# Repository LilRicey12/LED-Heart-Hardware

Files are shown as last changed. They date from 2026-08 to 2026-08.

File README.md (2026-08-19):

# Hardware-Only Sequential LED Heart

## Project Status

Final Build

## Project Overview

This project involves designing and constructing a heart-shaped sequential LED display using hardware timing and digital logic rather than a programmable microcontroller.

A 555 timer will generate the clock signal, and a CD4017 decade counter will control the LED sequence. The final circuit will be transferred from a breadboard prototype to permanent construction and installed in a finished enclosure.

## Project Goals

* Design a repeating sequential LED effect
* Build the circuit without a microcontroller
* Learn how the 555 timer and CD4017 operate
* Test each circuit subsystem independently
* Transfer the working design to perfboard
* Produce a clean and reliable final assembly
* Document the complete engineering process

## Planned System

Power supply → 555 timer → CD4017 counter → LED output circuitry → Heart-shaped display

## Documentation

This repository will contain:

* Session logs
* Circuit calculations
* Schematics and block diagrams
* Breadboard prototypes
* Test results
* Troubleshooting records
* Perfboard layouts
* Construction photographs
* Final portfolio materials

## Current Stage

The local project workspace, OneDrive archive, and private GitHub repository have been established. Circuit development has not yet begun.

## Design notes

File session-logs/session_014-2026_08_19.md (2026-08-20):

# LED Heart — Session Log

## Session Information

**Session number:** 014
**Date:** 2026-08-19
**Time spent:** 7.5 Hours
**Project phase:** Final Build

## Objective

Finisht the circuit including a power supply and switch

## Starting Point

The majority of the circuit was complete. I had 30 underboard wires to connect and the battery/switch

## Work Completed

* Connected all wire nodes to corresponding resistor
* Practised connecting a battery and switch on scrap protoboard
* Connected battery and the switch to main board

## Engineering Decisions

### Decision Made

N/A

### Reasoning

N/A

## Calculations and Predictions

**Calculation or prediction:** N/A

**Expected result:** N/A

**Actual result:** N/A

## Testing

**What was tested:** Tested the circuit before completion

**How it was tested:** Roughly half way through connecting the nodes I connected the board to power to see if it was working

**Expected result:** Some of the LED's would turn on with the sequencing logic

**Observed or measured result:** The LED's did turn on with the logic, first try too

**Pass or fail:** Pass

## Problems Encountered

N/A

## Troubleshooting Process

N/A

## Changes Made

N/A

## Current Status

### Working

* The entire electrical component of the board is working

### Not Yet Working

* I need to assemble the case and fasteners for the perfboard

### Remaining Questions

* Its all just finishing up, everything I need to know I already now

## Next Session

Assemble the case/frame and connect the board

## Files Created or Updated

* Schematics: N/A
* Calculations: N/A
* Test results: N/A
* Photos: Added 5 photos and 4 videos to raw media folder
* Other: N/A

## Session Summary

This is extremely exciting, I'm actually so happy my perfboard layout actually worked. Overall today was an amazing session.

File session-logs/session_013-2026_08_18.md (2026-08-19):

# LED Heart — Session Log

## Session Information

**Session number:** 013
**Date:** 2026-08-18
**Time spent:** 10 Hours
**Project phase:** Final Build

## Objective

Get as much work done on the final project as possible

## Starting Point

I had practised soldering techniques, planned extensively, mentally preped myself for the final build

## Work Completed

* Complete the LED Heart Hardware up both ICs, full component layout, rails, and mostly connected everything. The only things not connected are Q outputes and diode node to resistors. A total of 30 LEDs
*
*

## Engineering Decisions

### Decision Made

Finish as much as I could today

### Reasoning

This decision is mostly a deadline thing. This LED Heart is a portfolio project yes, but it is also a gift. It is a gift that needs to be ready in 3 days. If I didn't just say "fuck it" and dedicate a full day I believe the deadline would not be met.

## Calculations and Predictions

**Calculation or prediction:** N/A

**Expected result:** N/A

**Actual result:** N/A

## Testing

**What was tested:** N/A

**How it was tested:** N/A

**Expected result:** N/A

**Observed or measured result:** N/A

**Pass or fail:** N/A

## Problems Encountered

* Soldered an LED backwards.
* Lifted a copper pad
* Accidentally misassigned the GND/PWR rails opposite to my perfboard layout
* Tried testing the oscillating output circuit without the IC in the socket..
* Had some weird reading on the oscillating output circuit

## Troubleshooting Process

* Who ever made solder wick needs a nobel prize
* I had to use a small solid core wire to bridge across the lifted pad
* This was actually a large headache. By the time I noticed all the LEDs and capacitors were wired to "GND". It became a decision of undo all of that work, or improivse my design. I ended up improvising my design, the to IC circuits are now slightly different then how they are in the layout. Depending on how things go I plan to update the layout with the new design before closing the project
* This was annoying as well. I was checking the output with a multimetre and the value kept oscillating between 3.1 and 3.7. I found this odd so I made a small led circuit on a breadboard and connected it to the output and it worked perfectly. After some research I found that my multimetre could not keep up with how fast the oscillating was so it was averaging a value. That is what caused the weird readings.

## Changes Made

Some on the fly changes needed to be made because of my mistake. Design layout for the to IC are now different then the perfboard layout

## Current Status

### Working

* Oscillating circuit is the only thing I've explicit verified works, but the LEDs and fade should both work

### Not Yet Working

* The CD4017 outputs have not been connected, as well as the diode node to the resistors for the LED

### Remaining Questions

* The only thing im a bit ambigiuos about it how I am going to install the switch, battery, and frame/case for the perfboard

## Next Session

Next session will be completing the full circuit. This mainly includes hooking up 30 wires and connecting the battery/switch

## Files Created or Updated

* Schematics: N/A
* Calculations: N/A
* Test results: N/A
* Photos: Added 12 photos and 1 video to raw-media folder
* Other: N/A

## Session Summary

This was a long one. Honestly though it was very enjoyable, I found myself more engaged with this session then any others. Something about the almost month of work I put into this coming into its finale is very special. I can't wait to get back at it tomorrow, one step closer to the closing this project.

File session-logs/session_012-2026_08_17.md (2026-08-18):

# LED Heart — Session Log

## Session Information

**Session number:** 012
**Date:** 2026-08-17
**Time spent:** 3 Hours
**Project phase:** Prototyping

## Objective

Fully solder the NE555 oscillating output circuit

## Starting Point

I had the NE555 timer fully modelled on a digital perfboard

## Work Completed

* Completely soldered the NE555 timer circuit
*
*

## Engineering Decisions

### Decision Made

N/A

### Reasoning

N/A

## Calculations and Predictions

**Calculation or prediction:** N/A

**Expected result:** N/A

**Actual result:** N/A

## Testing

**What was tested:** Creating the NE555 timer circuit

**How it was tested:** Reading a blueprint and soldering

**Expected result:** I would get it working

**Observed or measured result:** I got it working

**Pass or fail:** Pass

## Problems Encountered

* I accidently soldered discharge to the wrong node
* I accidently soldered threshold to the wrong node
* The LED turned on but didnt blink

## Troubleshooting Process

* Solderwick, solder-sucker, and struggle
* Solderwick, solder-sucker, and struggle
* I didn't have a clean connection from the resistor to power rail, this caused the capacitor not to get charged. Since the voltage never got over 1/3 Vcc trigger never triggered.

## Changes Made

No changes in the project as a whole

## Current Status

### Working

* NE555 Timer circuit practise

### Not Yet Working

* Main board hasn't been started

### Remaining Questions

* Will it be alright to use solder as connections under the board. How do I properly solder jumper wires under the board

## Next Session

Practise more soldering. Potentially start the main soldering

## Files Created or Updated

* Schematics: N/A
* Calculations: N/A
* Test results: N/A
* Photos: Added some pictures of the soldered NE555 in my raw-media folder
* Other: N/A

## Session Summary

Soldering is hard man. Although with enough patience it is definetly manageable. I ended up having to some particulary tight connections and joints. It all ended up working quite well though. The biggest issue was just trying to connect a 2D layout to a 3D board.

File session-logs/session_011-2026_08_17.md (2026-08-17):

# LED Heart — Session Log

## Session Information

**Session number:** 011
**Date:** 2026-08-17
**Time spent:** 5 Hours
**Project phase:** Modelling

## Objective

Create a final perfboard layout for the heart

## Starting Point

A breadboarded full circuit of the heart was made

## Work Completed

* Finished the perfboard layout for the project
*
*

## Engineering Decisions

### Decision Made

N/A

### Reasoning

N/A

## Calculations and Predictions

**Calculation or prediction:** N/A

**Expected result:** N/A

**Actual result:** N/A

## Testing

**What was tested:** N/A

**How it was tested:** N/A

**Expected result:** N/A

**Observed or measured result:** N/A

**Pass or fail:** N/A

## Problems Encountered

More or less the only problem was trying to keep the board organized well designing it. Having 20 LEDs, 20 resistors, 10 capacitors, 10 dioes. Among other things makes things messy quick. In all honesty its not cleanest even after being completed

## Troubleshooting Process

N/A

## Changes Made

No changes the the design have been made

## Current Status

### Working

* Perfboard layout, breadboard circuit

### Not Yet Working

* Haven't soldered yet

### Remaining Questions

* Well I know how I'm going to solder it now. The really question is if I have the skill to. Some of the joints, connections, and what not don't leave much room for error.

## Next Session

Next session will be a short session. I will be practising some of the nodes and connections I will be making in the main project. I will also be fully soldering the NE555 timer circuit on a scrap perfboard, as I think that will be a little tricky

## Files Created or Updated

* Schematics: At the perfboard layout in design/perfboard-layout
* Calculations: N/A
* Test results: N/A
* Photos: Added 3 photos of the layout in my raw-media folder
* Other: N/A

## Session Summary

This was a PAIN in the ass. From here on out I vow to never take on a pure hardware project EVER again.

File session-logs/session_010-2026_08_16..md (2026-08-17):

# LED Heart — Session Log

## Session Information

**Session number:** 010
**Date:** 2026-08-16
**Time spent:** 5.5 Hours
**Project phase:** Prototyping

## Objective

Finish the entire circuit on a breadboard

## Starting Point

Initial wiring schematic was completed

## Work Completed

* Created the full circuit on a breadboard
* Tested component values
* Updated wiring schematic to final version

## Engineering Decisions

### Decision Made

N/A

### Reasoning

N/A

## Calculations and Predictions

**Calculation or prediction:** N/A

**Expected result:** N/A

**Actual result:** N/A

## Testing

**What was tested:** Different capacitor and resistor values. This was for the fade effect and oscillating output timing

**How it was tested:** It was tested by simply changing different values and observing the effect it makes. I used this to nail in what I think looked good

**Expected result:** N/A

**Observed or measured result:** I ended up going with a 1k ohm resistor for R1 and a 220 ohm resistor for R2 with a 100uF capacitor in the oscillating output circuit. For the light fade I used a 470 ohm resistor for each LED with a 470uF capacitor for every two LEDs

**Pass or fail:** Pass

## Problems Encountered

* NE555 was not outputting a voltage
* Circuit was behaving weirdly when I attached the CD4017
* I wasn't getting a voltage to the LED despite the output having a correct voltage
* My LEDs where not matching with the numbers of outputs I had

## Troubleshooting Process

* I'm actually not to sure why this happened. It was fixed by disconnecting the CONTROL pin from ground, I had it initial through a small capacitor then to ground. By simply removing it it made the circuit work perfectly
* Stupid little issue, I had the CD4017 placed backwards, my guess is that the way the pins where lined up it was causing a really high load which was causing issues
* Another stupid little issue, I didn't have the CD4017 placed deep enough into the breadboard. This caused a proper reading on the pin, but the current didn't go to the LED
* This one is as simple as engineering students can't count. I accidently used 18 LEDs instead of the full 20. I just ended up connected Q9 to the RESET pin, this was because I didn't have space on the breadboard to neetly add 2 more LEDs

## Changes Made

* Removed the ground connection on the NE555 CONTROL
* Removed one of the CD4017 and instead connected 2 LED's to every output
* Changed the values of components on the schematic

## Current Status

### Working

* The breadboard is working perfectly, even after extended use (I left it on for 2 hours)

### Not Yet Working

* I haven't started soldering it yet

### Remaining Questions

* How the hell am I going to solder this thing

## Next Session

Next session I will be using DIY Layout Creator to model the entire perfboard.

## Files Created or Updated

* Schematics: Added final schematic in design/schematic
* Calculations: N/A
* Test results: N/A
* Photos: Added 7 photos to my raw media folder, added 2 videos to my raw media folder
* Other: Created a backup of the entire project, and a backup of the KiCAD final design

## Session Summary

Man this was a long one. It was also really tedious stripping wire, cutting wire, cutting components, bending components, placing components. Despite the struggle it was at times now that its done it feels incredible. Now that I have the circuit fully complete and tested it makes it feel a lot more real.

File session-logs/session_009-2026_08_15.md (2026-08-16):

# LED Heart — Session Log

## Session Information

**Session number:** 009
**Date:** 2026-08-15
**Time spent:** 3 Hours
**Project phase:** Learning / Early Prototyping

## Objective

This session was dedicated to learning some soldering and experimenting with a circuit design software to plan the perfboard\

## Starting Point

No work in either of these aspects have been completed

## Work Completed

* Created a small solder project for practise
* Played around with DIY Layout Creator

## Engineering Decisions

### Decision Made

Decided to layout my perfboard before any soldering for it

### Reasoning

I'm not very good at soldering, so going into the final project I want to have as much work done as possible. This means I don't have to solve problems with soldering skill, but rather with good planning

## Calculations and Predictions

**Calculation or prediction:** N/A

**Expected result:** N/A

**Actual result:** N/A

## Testing

**What was tested:** N/A

**How it was tested:** N/A

**Expected result:** N/A

**Observed or measured result:** N/A

**Pass or fail:** N/A

## Problems Encountered

* Just soldering in general its pretty tricky

## Troubleshooting Process

* This will be something that comes with practice

## Changes Made

No changes to the project as a whole has been made

## Current Status

### Working

* The subsystmes have been tested

### Not Yet Working

* Heart hasn't started

### Remaining Questions

* How the hell am I going to solder this

## Next Session

Im going to revisit the wiring schematic. I'm planning to set up the LED Heart as a whole on breadboards, with this I can finalize component values. If I have time I will also start the perfboard design

## Files Created or Updated

* Schematics: N/A
* Calculations: N/A
* Test results: N/A
* Photos: N/A
* Other: N/A

## Session Summary

I've been wanting to actually get soldering for a while now, so it's really nice to actual get practising. I made a simple LED with an on/off switch, once It started working man that felt good.

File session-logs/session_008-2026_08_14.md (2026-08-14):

# LED Heart — Session Log

## Session Information

**Session number:** 008
**Date:** 2026-08-14
**Time spent:** 3.5 Hours
**Project phase:** Inital Design

## Objective

The original goal was to start soldering, but I got side tracked and started working with "TinkerCad" and "KiCad"

## Starting Point

Pretty much all the learning for the components has been learned

## Work Completed

* Created a breadboard layout in TinkerCad
* Created a whole project schematic in KiCad
*

## Engineering Decisions

### Decision Made

N/A

### Reasoning

N/A

## Calculations and Predictions

**Calculation or prediction:** N/A
 
**Expected result:** N/A

**Actual result:** N/A

## Testing

**What was tested:** N/A

**How it was tested:** N/A

**Expected result:** N/A

**Observed or measured result:** N/A

**Pass or fail:** N/A

## Problems Encountered

N/A

## Troubleshooting Process

N/A

## Changes Made

Mainly just fine tuning some designs. Things like adding a decoupling capacitor for the two CD4017 and the NE555

## Current Status

### Working

* The initial design is complete

### Not Yet Working

* I haven't actually tested the fade effect using capacitors. I also haven't tried making decoupling capacitors on a breadboard.

### Remaining Questions

* How the hell am I going to solder this

## Next Session

It will either be a session dedicated to soldering or a session where I test out the fade effect, cutting/sizing wires, and starting to plan out my perfboard wiring. I eventually need to finalize the values for the all the resistors and capaccitors I plan to use.

## Files Created or Updated

* Schematics: Uploaded a schematic in design/schematic
* Calculations: N/A
* Test results: N/A
* Photos: Uploaded a tinkerCad breadboard layout in design/schematic, Uploaded an image of the KiCad schematic in design/schematic
* Other: N/A

## Session Summary

Honestly KiCad is REALLY cool, its super fun messing around with it and I'm excited to play with it more in the future. Its also quite intuitive which helps a lot

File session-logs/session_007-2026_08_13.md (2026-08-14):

# LED Heart — Session Log

## Session Information

**Session number:** 007
**Date:** 2026-08-13
**Time spent:** 3 Hours
**Project phase:** Learning

## Objective

Complete an experiment with the CD4017, one involving creating a simple 5 LED discrete sequential LED activation, one involving using 2 CD4017 and a handoff

## Starting Point

I had written code for one experiment, simple oscillating output

## Work Completed

* Completed the first experiment
* Made changes to the project as a whole
*

## Engineering Decisions

### Decision Made

I changed the logic of how the heart will look. This involves using a bigger perfboard then planned. I also will not being using a handoff, instead use two CD4017 to have to seperate sequences of LEDs. I will not be making a faceplate out of wood, this will leave the front of the perfboard with the LED visible

### Reasoning

First why not a handoff? Well trying to design the handoff I ran into the issue I need some sort of flip-flop, whether I use transistors or a CD4013. I can't use the CD4013 as this project has a deadline and I won't be able to get the component in fast enough. I can't use transistors mostly because they are fairly complex, I plan to learn how to use them in a seperate project. I'm already learning ALOT as this is my first project so throwing in learning transistor is not feasibly. I'm going to use a bigger perfboard to be able to seperate the LED more this will make the soldering and wiring easier. I originally planned to make a wooden face plate with the LED poking through, however my wood working skills are not at that level, and once again I don't have the time to learn

## Calculations and Predictions

**Calculation or prediction:** N/A

**Expected result:** N/A

**Actual result:** N/A

## Testing

**What was tested:** Use the CD4017 to make a sequential LED activation

**How it was tested:** Check the CD4017 Experiment 1 in testing/experiments

**Expected result:** It would work

**Observed or measured result:** It did work

**Pass or fail:** Pass

## Problems Encountered

* At first none of the LED turned on

* LED position Q0 and Q4 where not turning on

## Troubleshooting Process

* My first issue was quite silly. Instead of using the CD4017 I accidently used a CD4017 IC socket

* Q0 wasn't turning on because I had the LED polarity backwards, Q4 wasn't turning on because I originally had Q4 connected to an LED and the rest. By moving the reset to Q5 it worked fine

## Changes Made

Changes to the project as a whole were mentioned in "Decisions'

## Current Status

### Working

* The NE555 is ready, as well as the CD4017

### Not Yet Working

* The main project hasn't been started

### Remaining Questions

* How the hell do I solder

## Next Session

Next session I'm going to practise soldering, likely will just solder random simple circuits just to get a feel for it

## Files Created or Updated

* Schematics: N/A
* Calculations: N/A
* Test results: Experiment recorded in testing/experiments
* Photos: A photo and a video uploaded into raw-media in OneDrive
* Other: N/A

## Session Summary

This was stressful. I thought the project was sorta ruined when I realized I would need more components for the sequencing logic. I had to figure out a pivot to make it viable to finish it by the deadline (When I go back to school). I think I got it mostly figured out though.

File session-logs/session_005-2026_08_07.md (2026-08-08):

# LED Heart — Session Log

## Session Information

**Session number:** 005
**Date:** 2026-08-07
**Time spent:** 3 Hours
**Project phase:** Learning

## Objective

Create and experiment with a oscillating output using the 555 timer 

## Starting Point

I have a very good understanding of how the 555 timer works logically

## Work Completed

* Created the oscillating output
* Created and completed an experiment involving the circuit

## Engineering Decisions

### Decision Made

Createed and understood the oscillating output

### Reasoning

This output is a very crucial part of the project as a whole so knowing everything about it is very important

## Calculations and Predictions 1

**Calculation or prediction:** N/A

**Expected result:** N/A

**Actual result:** N/A

## Testing 1

**What was tested:** An oscillating output

**How it was tested:** I followed a common wiring schematic, check NE555 Experiment 4

**Expected result:** We would make an LED blink

**Observed or measured result:** The result was as expected

**Pass or fail:** Pass

## Problems Encountered 1

* I couldn't notice the blinking at first, I didn't know if it was working or not.

## Troubleshooting Process 1

* I used a much larger timing capacitor this made the blinking much more obvious

## Calculations and Predictions 2

**Calculation or prediction:** N/A

**Expected result:** N/A

**Actual result:** N/A

## Testing 2

**What was tested:** What the 2 resistors in the wiring circuit do

**How it was tested:** I changed the resistors out and recorded the result

**Expected result:** I thought one resistor would control on time and one would control off time

**Observed or measured result:** It was a bit more complicated then that. The discharge of the capacitor is timed by R2 and the charge is timed by R1+R2

**Pass or fail:** Pass

## Problems Encountered 2

* I had issues tracing the circuit, I saw the capacitor was grounded so I didn't understand what the discharge pin did.
* I couldn't figure out how the resistors changed time

## Troubleshooting Process 2

* I had to do some research into capacitors, this taught me that the current doesn't flow through the capacitor like a diode or resistor. Rather the capacitor consists of 2 plates seperator by a plate where ideally the charge can't cross. One side has the stored voltage and in really simple terms the other plate attracts the voltage to go into the other plate. All in all when discharge pin is active both plates are in a GND state so the current flows into it
* This was very related to learning how capacitors work, using test data, and studying the wiring schematic. Once all of that was done it wasn't to hard to figure out what each resistor does

## Changes Made

No changes to project as a whole have been made

## Current Status

### Working

* All 555 Timer Circuit study has been completed

### Not Yet Working

* Main heart hasn't been started

### Remaining Questions

* How does the CD4017 work

## Next Session

Start research on the CD4017

## Files Created or Updated

* Schematics: The oscillating timer circuit uploaded to design/schematic
* Calculations: N/A
* Test results: 2 Experiments added to testing/experiments
* Photos: 1 photo and 2 videos added to raw media file
* Other: Full project backup has been made

## Session Summary

Very exciting lesson. I finally finished my work with the 555 timer circuit.

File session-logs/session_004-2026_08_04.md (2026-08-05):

# LED Heart — Session Log

## Session Information

**Session number:** 004
**Date:** 2026-08-04
**Time spent:** 1 Hour
**Project phase:**  Learning

## Objective

Learn the internal logic of the 555 Timer

## Starting Point

Knew what each pin did and had some relevant experiments ran that helped understanding the internal logic

## Work Completed

* Took notes on the internal logc
*
*

## Engineering Decisions

### Decision Made

Just studied lol

### Reasoning

Engineering students LOVE to study

## Calculations and Predictions

**Calculation or prediction:** N/A

**Expected result:** N/A

**Actual result:** N/A

## Testing

**What was tested:** N/A

**How it was tested:** N/A

**Expected result:** N/A

**Observed or measured result:** N/A

**Pass or fail:** N/A

## Problems Encountered

N/A

## Troubleshooting Process

N//A

## Changes Made

N/A

## Current Status

### Working

* I have a much better understanding of the 555. I haven't gone deep enough like into a transistor-by-transistor schematic, but I know how the logic behind it works

### Not Yet Working

* Main heart hasn't been started

### Remaining Questions

* How do I make an LED blink with this thing

## Next Session

Probably make an LED blink we will have to see what I get up to though.

## Files Created or Updated

* Schematics: N/A
* Calculations: N/A
* Test results: N/A
* Photos: NE555 Timer Circuit, internal logic diagram added to raw-media/photos on cloud
* Other: More 555 Notes in docs/learning-notes

## Session Summary

Good short session. Had a long work day and didn't feel like I had the mental energy to run tests. I decided to look into the internals of the 555 since I always wanted to see and just kept putting it off to do more exciting things.

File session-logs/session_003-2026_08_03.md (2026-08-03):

# LED Heart — Session Log

## Session Information

**Session number:** 003
**Date:** 2026-08-03
**Time spent:** 50 Mins
**Project phase:** Learning

## Objective

Learn more about the 555 timer

## Starting Point

Started research into the 555 timer

## Work Completed

* Completed a short experiment

## Engineering Decisions

### Decision Made

Decided to do another experiment

### Reasoning

I need more time and knowledge to call the 555 an IC I truly understand

## Calculations and Predictions

**Calculation or prediction:** N/A

**Expected result:** N/A

**Actual result:** N/A

## Testing

**What was tested:** A Manual Set and Reset for the 555

**How it was tested:** Using a pushbuttons among other things refer to testing/experiments for full lab

**Expected result:** I could use a pushbutton and electrical node to manually trigger what state the internal SR latch was in

**Observed or measured result:** The latch behaved as expected

**Pass or fail:**

## Problems Encountered

* First issue the LED did not turn on
* Second issue the LED did not turn off

## Troubleshooting Process

* The first issue was any easy fix I simply didn't have the ground pin connected a ground
* The second issue was also quite an easy fix. Since the LED wouldn't turn on I assumed it was an issue with the trigger pin. Upon checking I noticed the pushbutton was wired wrong. This made it so pin 2 was constantly in a state of LOW voltage effectively telling the latch to stay open constantly. Fixing the button fixed the issue

## Changes Made

No changes in the project as a whole occured

## Current Status

### Working

* More knowledgable about the 555

### Not Yet Working
 
* The heart hasn't been started

### Remaining Questions

* Mainly just transistors, but I'm planning to put those of since they are only used in the internal circuitry of the 555 for this project so a deep level understanding iss not needed.

## Next Session

Test the 555 timer circuit more

## Files Created or Updated

* Schematics: N/A
* Calculations: N/A
* Test results: 1 tests uploaded in testing/experiments
* Photos: 3 phots unploaded in raw media cloud folder
* Other: N/A

## Session Summary

Short little session. Im going to the movie theatre today. Will probably have another session when I get back.

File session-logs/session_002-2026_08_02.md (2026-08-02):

# LED Heart — Session Log

## Session Information

**Session number:** 002
**Date:** 2026-08-02
**Time spent:** 3.5 Hours
**Project phase:** Learning

## Objective

The goal was mainly to finish some tweaks with documentation, then start work understanding the NE555 Timer Circuit

## Starting Point

Most of the setup for the documentation was done, no work with the timer has been started

## Work Completed

* First Document Backup Completed
* Learned all about the 555 timer
* Completed two small introductory experiments, these experiments did not involves the functions of the relay
* Learnt a naming format for media, inlcuding experiement notes, learnring notes, and photos

## Engineering Decisions

### Decision Made

Don't learn the more complex functions of the timer, until I have a better understanding of how is works

### Reasoning

Just simply knowing how something works isn't enough, you have to know why it works. By doing this these small experiments I not only get more practise setting up experiments, I also get a better understading of the IC. The way I see if I where to rush and just figure out how to use the 555 for this project I wouldn't be able to incorporate this IC into other projects. Lay the ground work now benefit from it later.

## Calculations and Predictions

**Calculation or prediction:** N/A

**Expected result:** N/A

**Actual result:** N/A

## Testing 1

**What was tested:** By connecting the power, ground, and reset pin I can turn on an LED through the output

**How it was tested:** I used the Arduino Uno microcontroller board as a power supply, then connected the pins to see if the LED would stay on consistantly

**Expected result:** LED would turn and stay on

**Observed or measured result:** LED did turn on and stayed on consistantly

**Pass or fail:** Pass

## Problems Encountered 1

N/A

## Troubleshooting Process 1

N/A

## Calculations and Predictions 2

**Calculation or prediction:** N/A

**Expected result:** N/A

**Actual result:** N/A

## Testing 2

**What was tested:** How does powering on LED through the 555 affect its current, voltage, and power compared to a direct power supply

**How it was tested:** I tested it through many means, refer to subsystems-tests for full lab

**Expected result:** The current and power would slightly decrease from the output stage of the 555

**Observed or measured result:** The current and power decreased a lot more then I thought roughly 55.5% for both current and power

**Pass or fail:** Pass

## Problems Encountered 2

* First issue I have having was that the LED would stay on even if I disconnected the ground
* Second issue measuring he voltage was a struggle trying to figure out where to place both prongs of the multimetre to get the desired date to a bit
* Third issue the voltage I was getting for my supply was around 3.5 volts well using the 5 volts output pin on the arduino

## Troubleshooting Process 2

* I tried using the discharge pin to drop any voltage that might be in the capacitor, that didnt work
* I grounded both the threshold and trigger pin and that ended up making it so the LED turned off when the ground disconnected. This made me more confident in the setup for the experiment
* Instead of using an external battery plugged into the barrel conncector I used the usb connections and plugged it into my labtop this turned the voltage to 4.44 volts which I found acceptable

## Changes Made

* No changes to the project as a whole have occured, did add a new folder under docs for learning notes and one for experiments under testing

## Current Status

### Working

* The documentation system is up and running

### Not Yet Working

* The project for the heart itself hasn't been started

### Remaining Questions

* How does the internal wiring of the 555 timer work
* Why are capacitors and ESPECIALLY transistors so important and what do they do
* How does the 555 timer work as a whole

## Next Session

Working on the more complex systems of the 555 timer, as well write short mark up for experiments

## Files Created or Updated

* Schematics: N/A
* Calculations: N/A
* Test results: 2 tests uploaded in testing/experiments
* Photos: 2 phots unploaded in raw media cloud folder
* Other: Todays notes uploaded in docs/learning-notes

## Session Summary

I really enjoyed putting my skills I've learnt from in school labs to use outside of it. Designing and completing questions, hypothesis, process, data, calculations, and results was quite fun. Overall this was a very proactive session.

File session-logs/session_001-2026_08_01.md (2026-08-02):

# LED Heart — Session Log

## Session Information

**Session number:** 001
**Date:** 2026-08-01
**Time spent:** 4 Hours
**Project phase:** The Beginning

## Objective

Establish an effective format to store and share information for documentation of my engineering
projects. This format will be used for all future projects, including my initial project. This is the initial project project the LED-Heart-Hardware

## Starting Point

Starting idea of the full project exists. Materials where also purchased

## Work Completed

* Created a dedicated local engineering-project workspace.
* Created a separate OneDrive archive for raw media and backups.
* Created the project folder structure.
* Created the project README and project brief.
* Created a reusable session-log template. (The template currently being used lol)
* Created a GitHub account and installed GitHub Desktop.
* Initialized and published a private GitHub repository.
* Completed and verified the first commit-and-push workflow.

## Engineering Decisions

### Decision Made

Use separate systems for active project files, Git version control, and large-file backups.

### Reasoning

A reusable and structured model is needed to ensure clarity and ease for future projects. By spending more time creating said model in the beginning, in the future I will benefit by having a system that can be applied widely. The local folder provides an active workspace, GitHub records project history, and OneDrive stores raw photos, videos, exports, and emergency backups.

## Calculations and Predictions

N/A

## Testing

N/A

## Problems Encountered

The initial repository-creation path required correction to avoid creating a nested project folder.

## Troubleshooting Process

The repository was created using the existing LED-heart project directory I created rather than the default GitHub Desktop location.

## Changes Made

The project was converted from a normal local folder into a private Git repository connected to GitHub.

## Current Status

The initial template and workspace has been created.

### Working

* Local project workspace
* OneDrive archive
* GitHub Desktop
* Private GitHub repository
* Commit-and-push workflow
* Documentation templates

### Not Yet Working

* Circuit development has not begun
* Raw-media workflow has not yet been tested
* Emergency backup process has not yet been tested

### Remaining Questions

* How photos should be transferred, selected, renamed, and archived after each session
* How full-project emergency backups should be created

## Next Session

* Finalize the workspace including, the first emergency backup, test raw-media transfer, media naming, and select what should be photographed or ignored
* Start doing research for the circuitry. Mainly includes understanding and notetaking for the NE555 Timer Circuit

## Files Created or Updated

* `README.md`
* `docs/project-brief.md`
* `session-logs/session-template.md`
* `session-logs/session-001_2026-08-01.md`

## Session Summary

Realizing the importance of a workflow was a big lesson. Going into this I thought I'll just write some notes, takes some pictures, and throw them in a folder. After a discussion with a professional I realized the importance of a proper work environment. Learning how gitHub works also was not fun.

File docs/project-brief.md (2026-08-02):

# LED Heart Project Brief

## Project Name

Hardware-Only Sequential LED Heart

## Project Purpose

Design and construct a heart-shaped sequential LED display as my first engineering portfolio project.

The project will be built using hardware timing and digital logic rather than a programmable microcontroller. It will demonstrate circuit design, prototyping, testing, troubleshooting, soldering, permanent construction, and technical documentation.

## Intended Outcome

The finished device will display a repeating sequence of orange LEDs arranged in a heart shape.

The electronics will be concealed within a clean enclosure or backing structure, while the LEDs remain visible from the front.

## Core Architecture

The planned system consists of:

1. Battery-powered supply
2. 555 timer configured as an oscillator
3. CD4017 decade counter
4. LED output and current-limiting circuitry
5. Heart-shaped LED arrangement
6. Permanent perfboard construction
7. Finished enclosure or mounting structure

## Primary Requirements

* The sequencing system must operate without a microcontroller.
* The LEDs must illuminate in a predictable repeating sequence.
* LED current must remain within safe operating limits.
* The circuit must operate reliably from the selected power source.
* The final assembly must conceal most wiring and electronics.
* The battery and power switch must remain accessible.
* The project must be documented throughout development.

## Design Goals

* Use approximately 20 orange LEDs.
* Produce a single moving or comet-like lighting sequence.
* Maintain reasonably consistent LED brightness.
* Keep the circuit understandable and serviceable.
* Build and test individual circuit sections before combining them.
* Create a final result suitable for an engineering portfolio and job fair.

## Constraints

* This is my first permanent hardware-only electronics project.
* The circuit will initially be developed using a breadboard.
* Final construction will likely use perfboard.
* Component choices may be limited by parts already purchased.
* The enclosure must be achievable with my current fabrication skills.
* The circuit should avoid unnecessary complexity.

## Success Criteria

The project will be considered successful when:

* The complete LED sequence operates correctly.
* The circuit starts reliably when powered.
* No components overheat during extended operation.
* The soldered assembly passes continuity and functional testing.
* The enclosure protects and conceals the electronics.
* The final appearance is clean enough for portfolio presentation.
* The design process, failures, revisions, and results are documented.

## Planned Development Stages

1. Define requirements and desired LED behaviour.
2. Learn and test the 555 timer circuit.
3. Learn and test the CD4017 counter.
4. Test individual LED output stages.
5. Combine the timing and counter circuits.
6. Develop the complete breadboard prototype.
7. Create the final schematic.
8. Plan the perfboard layout.
9. Assemble and solder the permanent circuit.
10. Test and troubleshoot the permanent assembly.
11. Build and install the enclosure.
12. Perform final validation and portfolio documentation.

## Current Status

The project folder structure and documentation system have been created. Circuit development has not yet begun.

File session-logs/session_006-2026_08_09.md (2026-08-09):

# LED Heart — Session Log

## Session Information

**Session number:** 006
**Date:** 2026-08-09
**Time spent:** 1.5 Hours
**Project phase:** Learning

## Objective

Learn the CD4017

## Starting Point

Just finished learning the NE555

## Work Completed

* Completed Notes on the CD4017
* Designed, but did not complete an experiment for the CD4017 IC

## Engineering Decisions

### Decision Made

N/A

### Reasoning

N/A

## Calculations and Predictions

**Calculation or prediction:** N/A

**Expected result:** N/A

**Actual result:** N/A

## Testing

**What was tested:** N/A

**How it was tested:** N/A

**Expected result:** N/A

**Observed or measured result:** N/A

**Pass or fail:** N/A

## Problems Encountered

N/A

## Troubleshooting Process

N/A

## Changes Made

No changes made to the project as a whole

## Current Status

### Working

* I have a better understanding of the CD4017

### Not Yet Working

* Haven't actually tested it yet

### Remaining Questions

* How can I make 2 CD4017 act after each other in sequence

## Next Session

Do some experiments with the CD4017

## Files Created or Updated

* Schematics: N/A
* Calculations: N/A
* Test results: N/A
* Photos: N/A
* Other: Added a .cpp file for the code for my next test in testing/experiments. Added my learning notes for the CD4017

## Session Summary

Short little session after work. Got started on the next big part of the project.

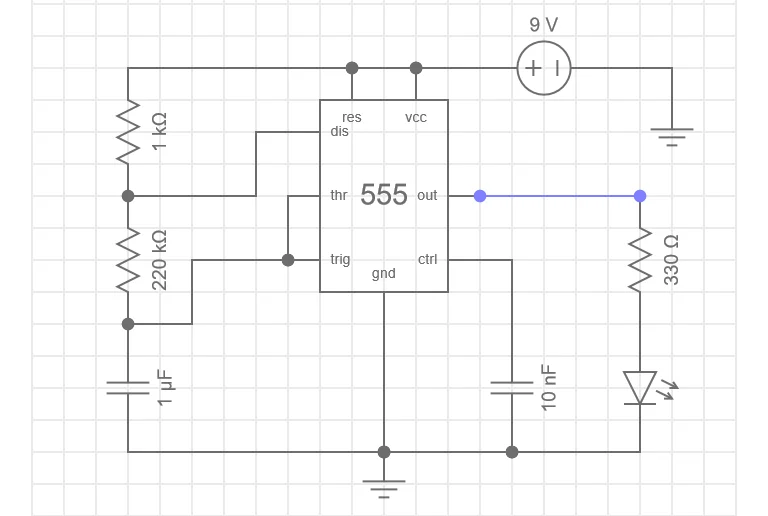
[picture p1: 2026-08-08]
design/schematics/NE555 Oscillating Output.webp

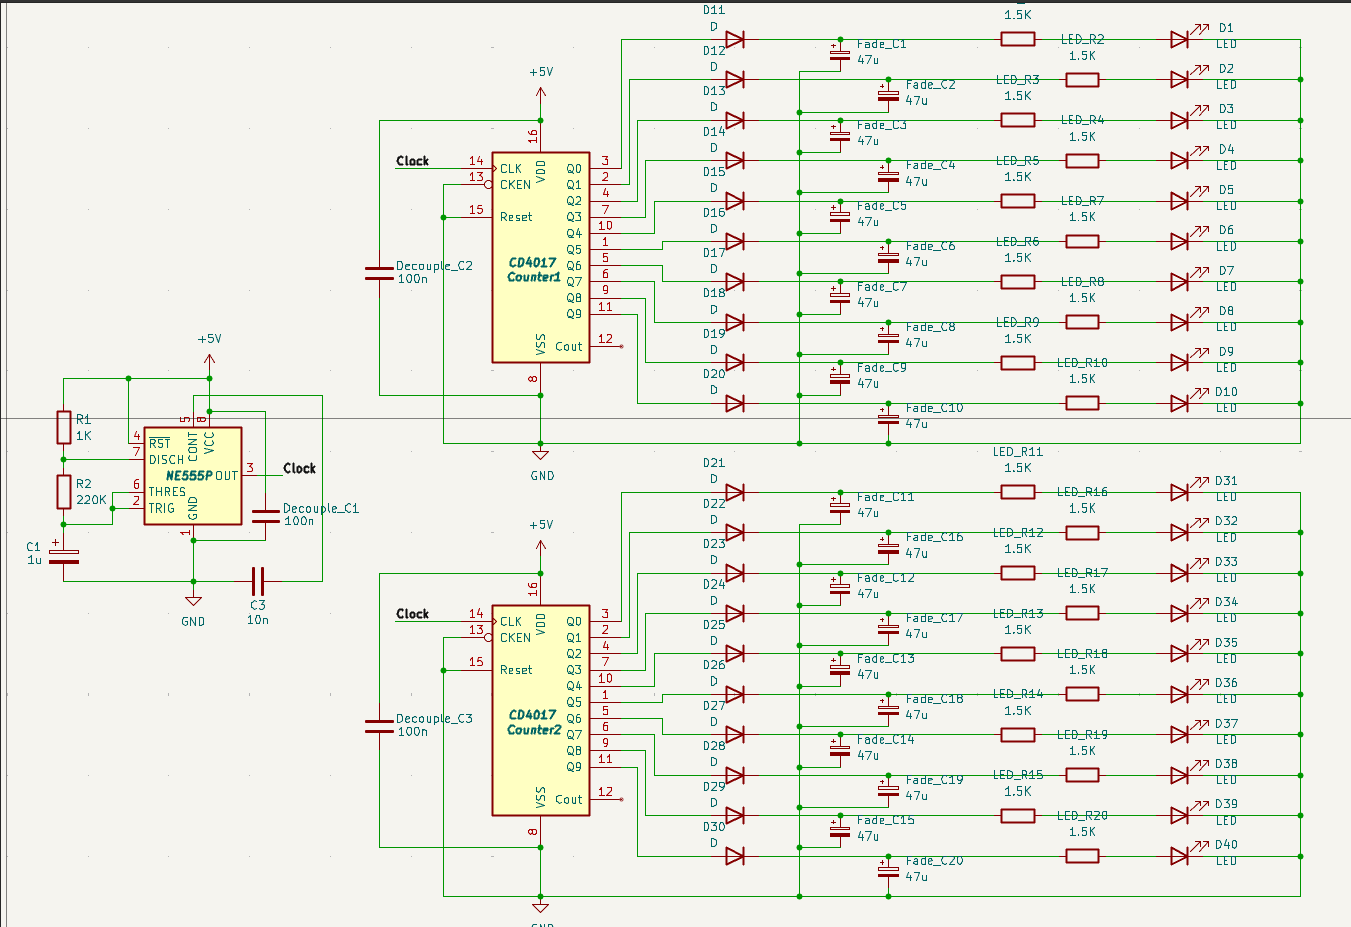
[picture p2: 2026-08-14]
design/schematics/LED_Hardware_Heart-First_Design-Image.png

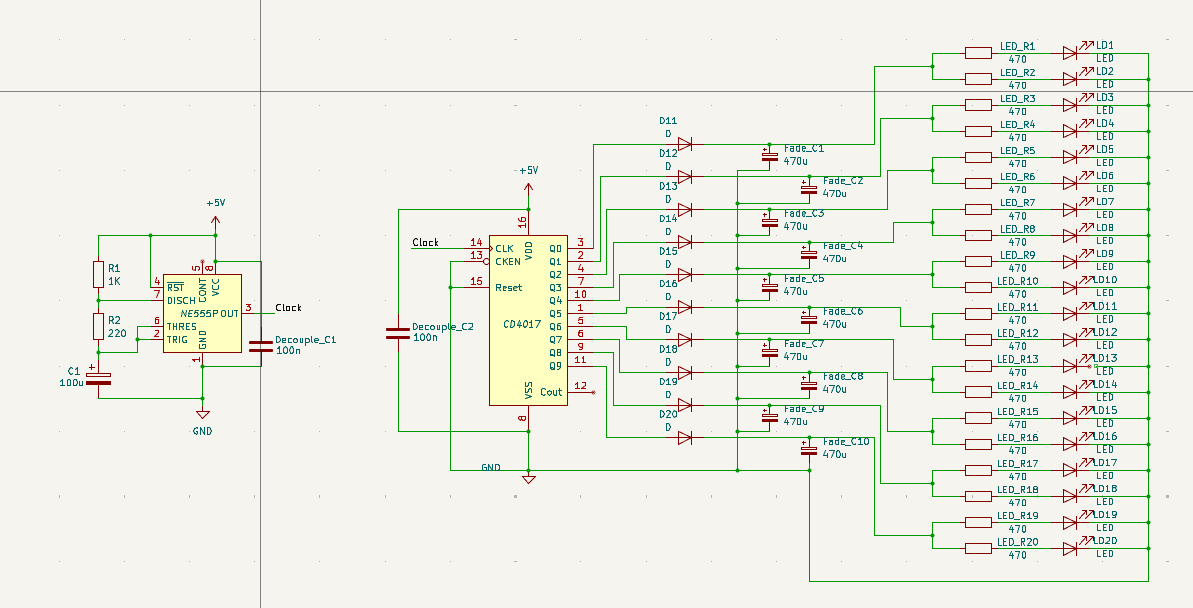
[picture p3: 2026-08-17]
design/schematics/LED_Hardware_Heart-Final Design-Image.png

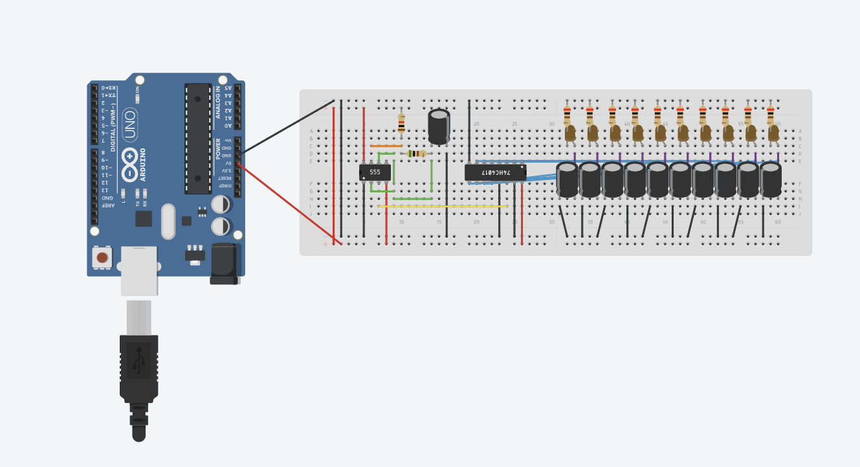
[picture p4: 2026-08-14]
design/perfboard-layout/Breadboard Layout Prototype.png

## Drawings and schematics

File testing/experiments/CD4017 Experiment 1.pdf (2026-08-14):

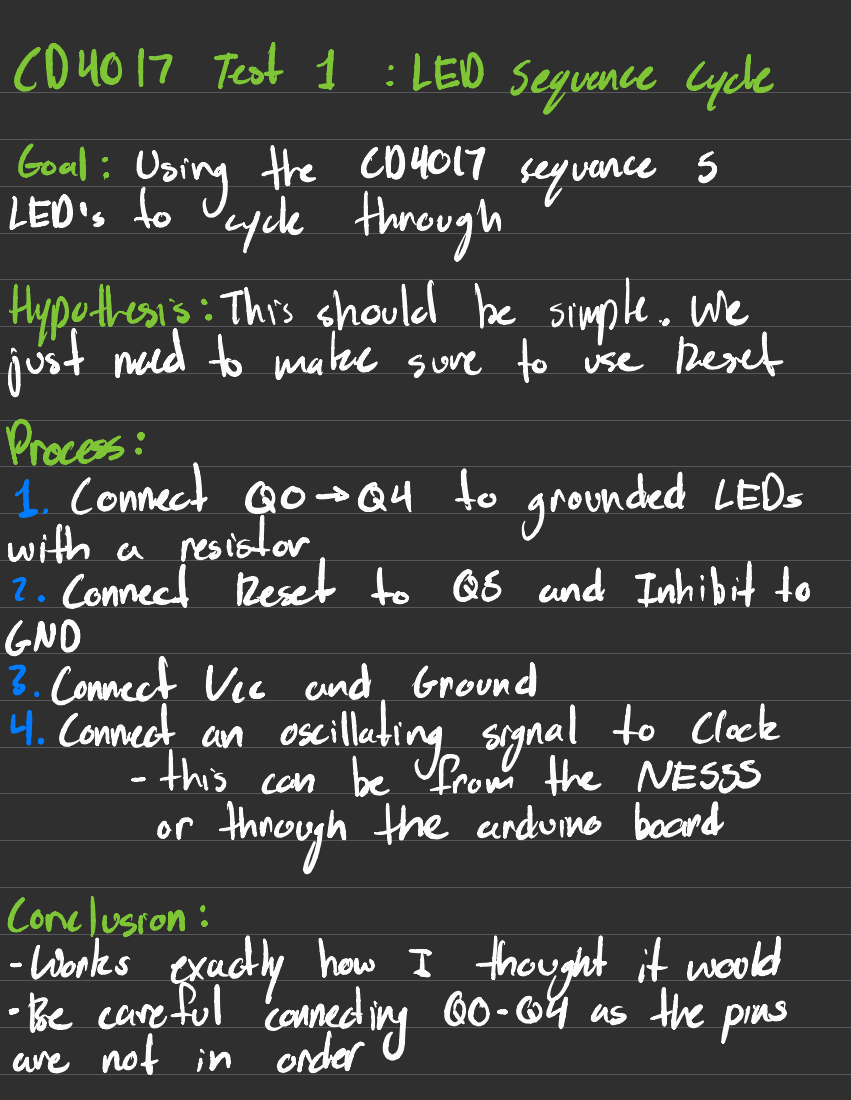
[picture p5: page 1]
through; Hypothesis :This should be simple .; just need to make sure to use; beset; with a; resistor; Connect an; oscillating signal to clock; this can; be from the NESSS; Conclusion :; the careful; Q0-04 as the connecting; pins; are not in; under

CD4017 Test 1 : LED Sequence cycle

Goal :
LED'sUsingthe CD401T sequasone

Process :
1. Connect 00-Q4 to grounded LEDs
2.Connect Reset to QS and Inhibit to
GND
3.Connect Ve and Ground
or through the anduine board
Works exactly how I

thought it would

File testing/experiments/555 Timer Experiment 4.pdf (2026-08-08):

# Oscillating output

# Goalcreata

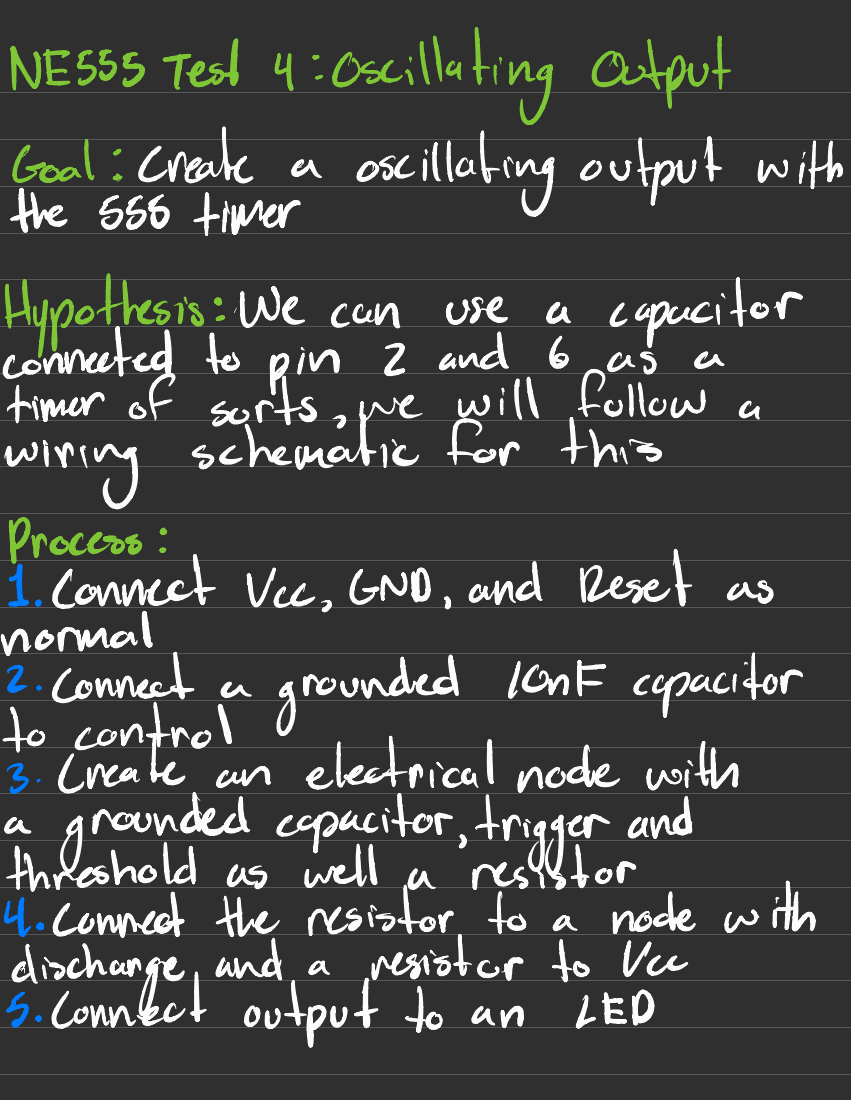
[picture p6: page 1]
NESSS Test 4 :; oscillating outputia; Hypothesis :We can; use a; capacitor connected; 2 and 6 as; threshold as well a; resister; 1.Connect the resistor to a; node with; resister to Ver discharge and; Connect output to an; LED

timer of topina we will follow a
schematic for this wining

Process :
.Connect Vac,
normal
2.Connect a
to control
3. create an electrical node with
grounded capacitor trigger and

and Reset as
GND ,
grounded lonF capacitor

When wired | it works correctly | perfect

## By changing capacitor change the frequency of the blinking -

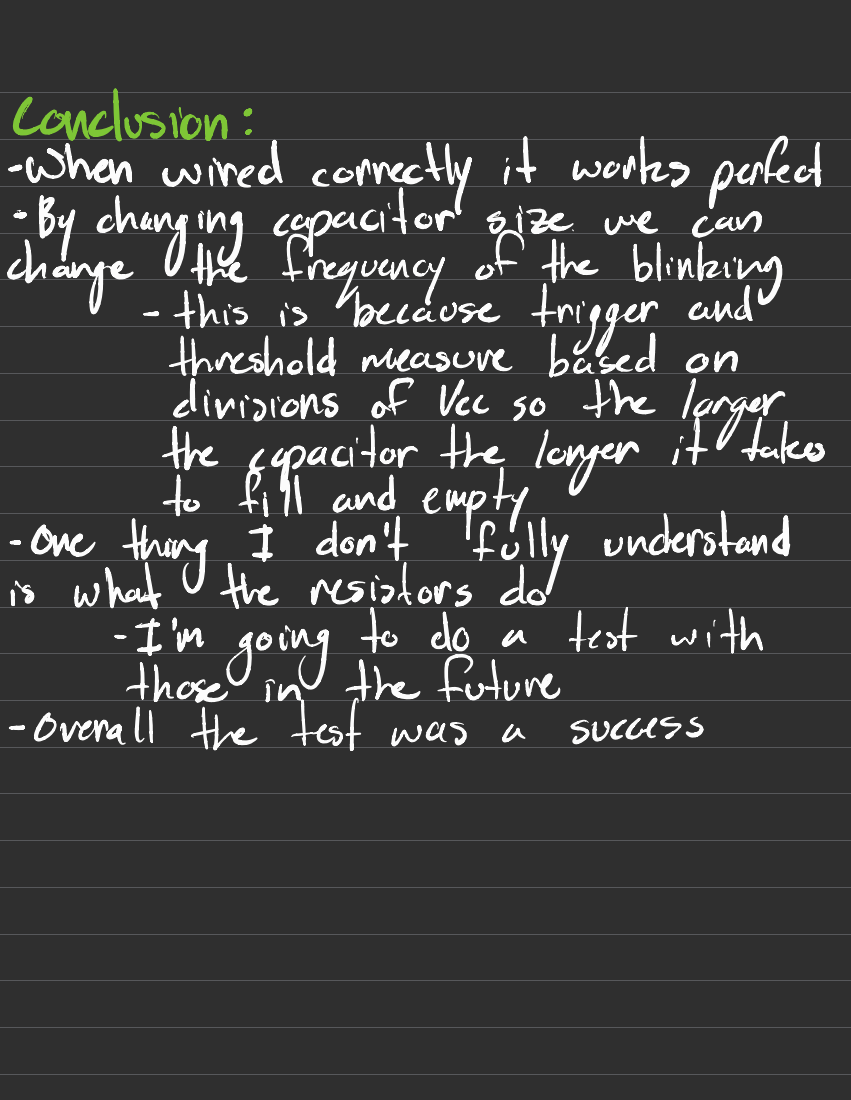
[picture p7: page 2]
conclusion :; this is; because; and trigger threshold measure based on; clivisions of Vec so; the; longer,; One; understand thing I don't; fully is; what the resistors do; test with going those in; the future -; overall the test was a; success

size we can ·

larger takes capacitor the

to fill and empty ·

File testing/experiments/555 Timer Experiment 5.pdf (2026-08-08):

# Question : In the oscillating output circuit

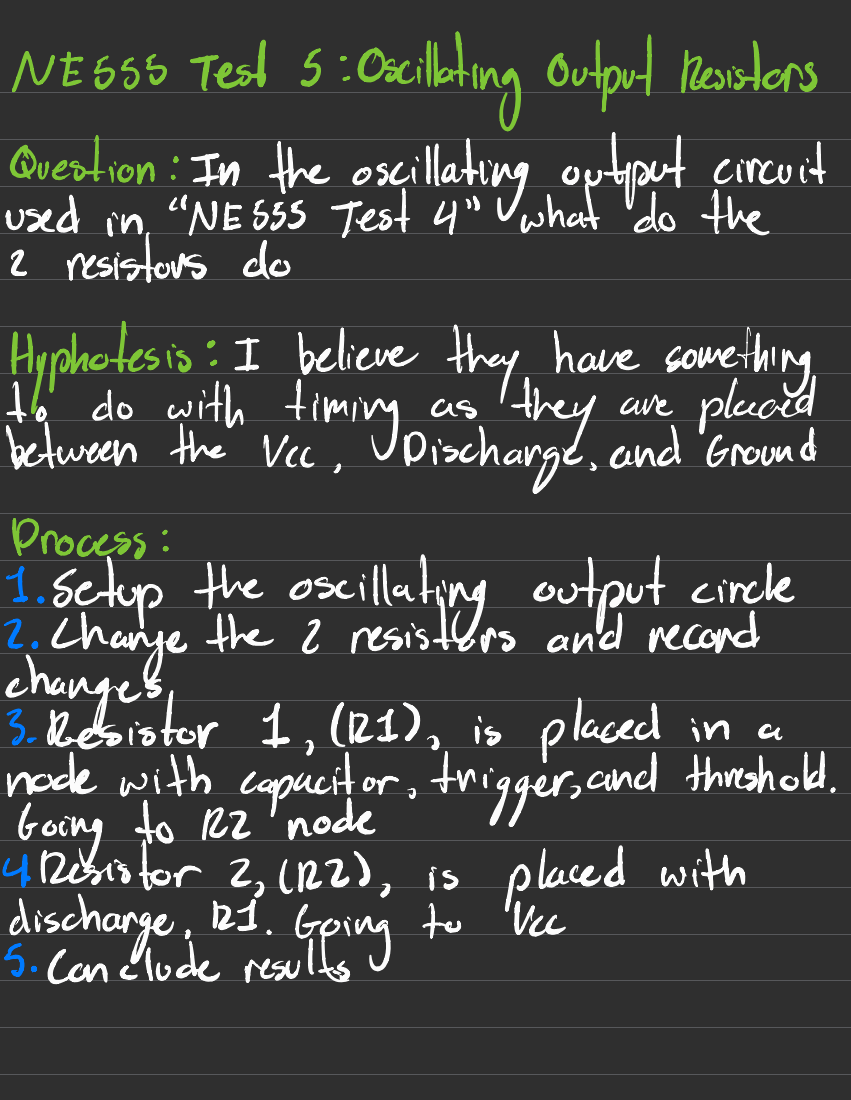
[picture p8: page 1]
resistors do; Hyphofesis : I believe they have something to do with; lad timing as; they ara p between the Vic ,; Discharge,; and Ground; is placed in a; trigger,; and threshold.; placed with

NESSS Test S :OscillatingOutput Resisters

used in "NESSS Test 4" What do the

Process :
2. oscillating autputcreate Change the
Setup the
changes 3.Resistor 1 ,
node with capacitor ,
R2 node Going to
. Resistor 2,
discharge ,
5.Conclude resulting

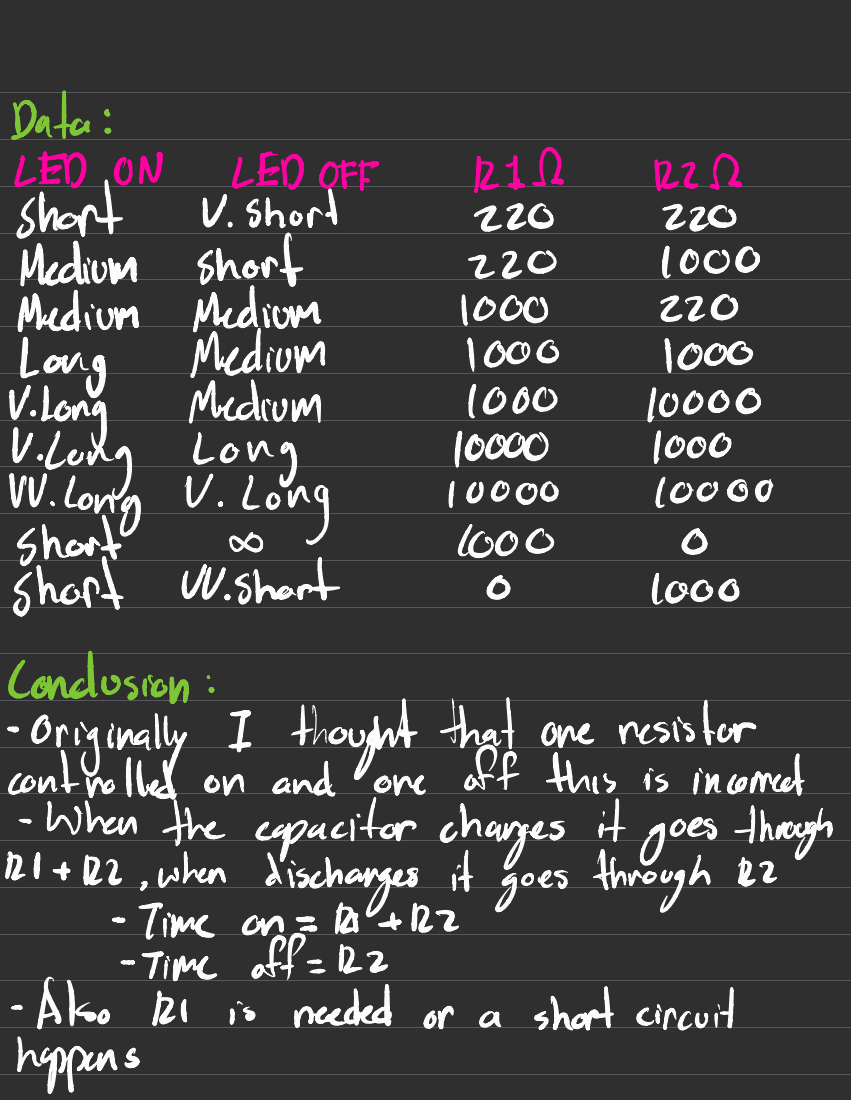
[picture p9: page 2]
Data :; LED ON; LED OFF; RES; RIM; Short; Medium shorf; Medium Medium; 1000 Long; Medium; Long Medium; 1000 Lang; 10008 Long VV.; 10008 Long V.; 10000 Long Short; Shart; controlled on and one; off this is incorrect -; goes through R2; Also R21 is; needed or a; short circuit

sharf WV.
Conclusion :
that one resistor thought ·
originally I
When the capacitor changes it
goes through 11 + 12 ,
when discharges it
Time on = Ro + R2
Time off= R2
happens

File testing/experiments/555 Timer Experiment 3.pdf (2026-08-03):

## NESSS Test 3 :Manual Set and Reset

### output and state of the 555 ?

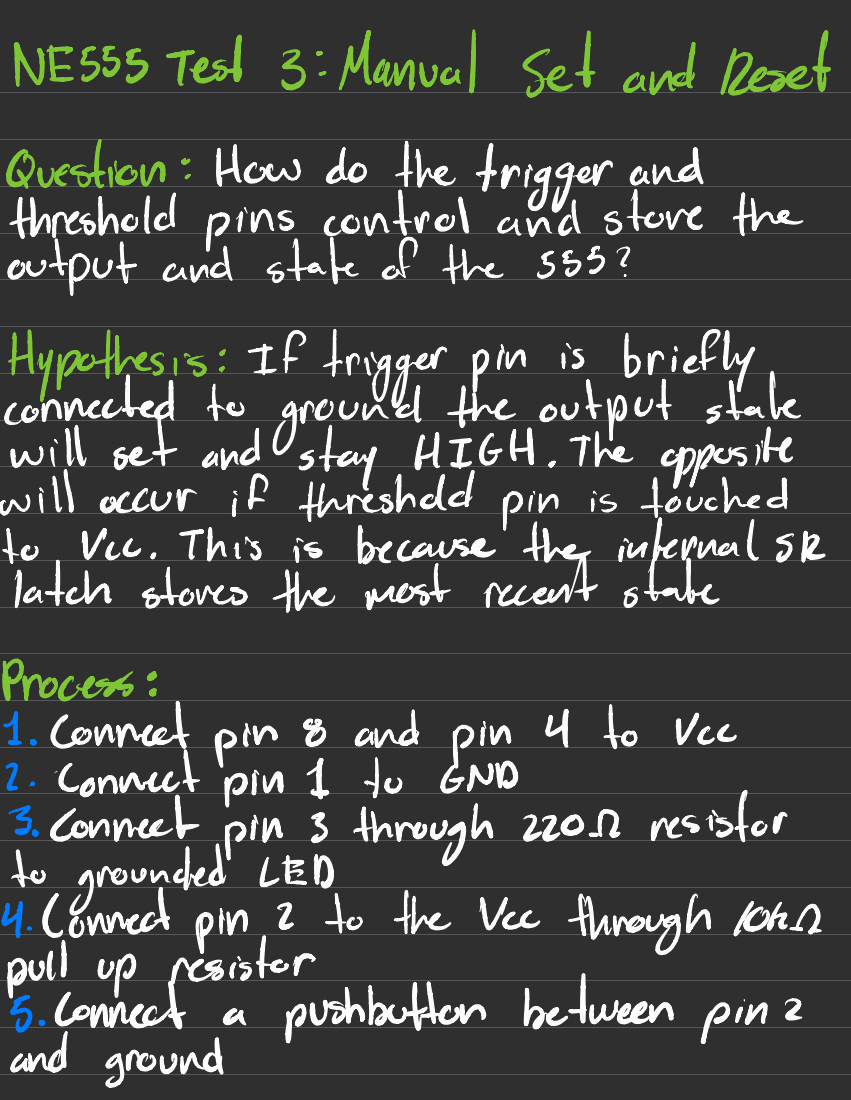
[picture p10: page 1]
Hypothesis : Iftrigger pin is; briefly connected to ground the output state; will set and stay HIGH .; The opposite will occur if threshold pin is touched; to Vic .; This is because the internal SR; 1 resistor; 5.Connect a; pushbutton between pinz and ground

Question : How do thetrigger and
threshold pins control and store the

latch stores the most recent state

Process :
Connect pin · and pin 4 to Vac
2 .Connect pin 7 to END
3.Connect pin 3 through 220.
to grounded LED
4.Connect pin z to the Van through 1861
pull up resister

## 6 . Connect pin 6 to ground through 10h.2 pulldown resistor

## 7.Connect a second pushbutton between

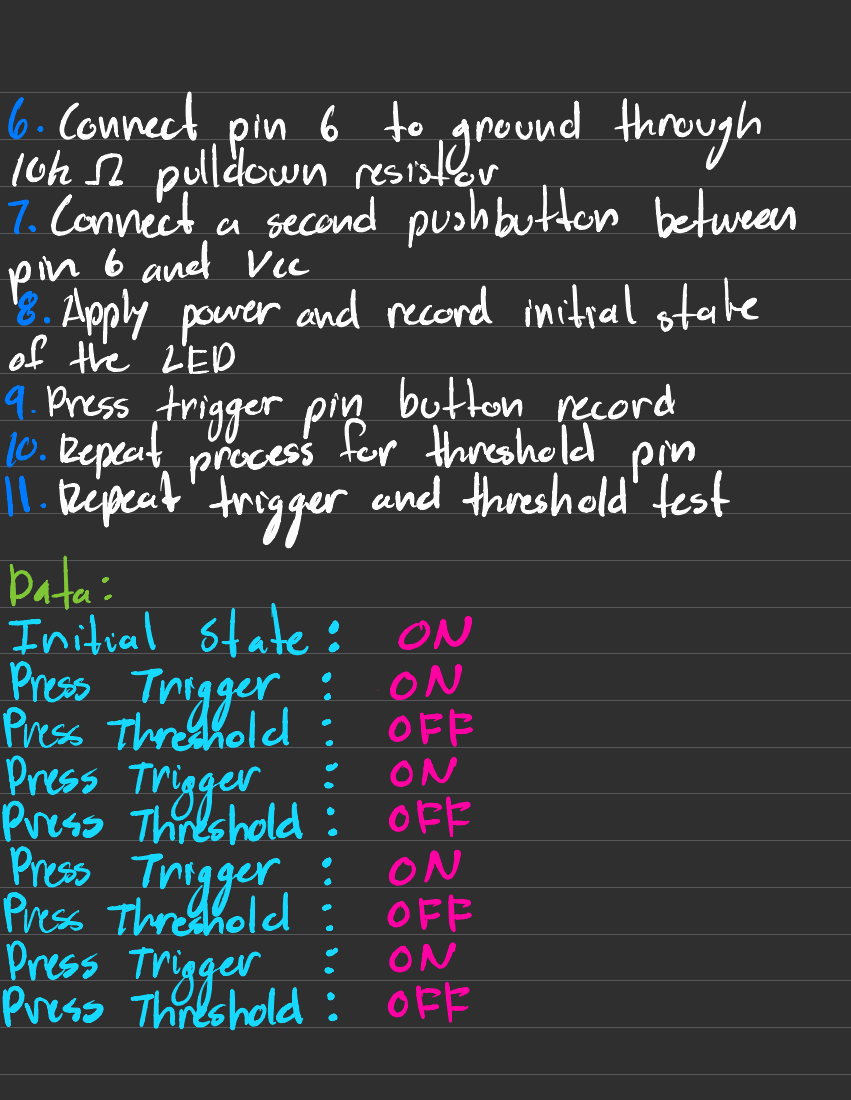
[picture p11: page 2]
Initial State :; Press Trigger 8; Press Threshold ·; OFF; Dress Trigger a; Press Threshold :

pin 6 and vac
Apply power and record initial state
of the LED
9.Press trigger pin button record
Repeat process
Repeat trigger and thresholdtest
Data :

for threshold pin

## The logic of the setup is that by using pushbuttons to provide a change in state

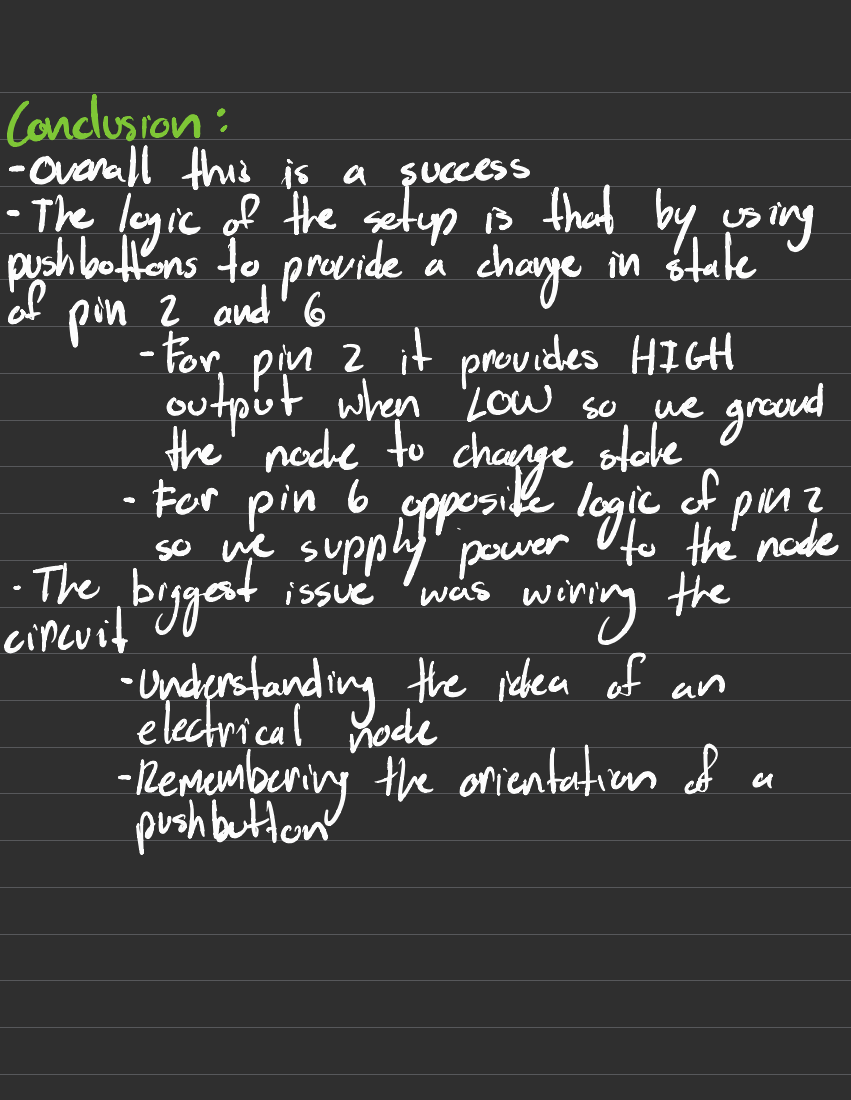
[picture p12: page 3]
Conclusion :; Overall this is a; success; For pin z; it provides HIGH; output when Low so; we ground the noche to change state -; For pin 6; opposite; of pinz; ↓ issue; was wiring the

of pin 2 and G

s wa supply powerlogic the node ·
The bigges circuit
understanding the idea of an
electrical noche
-Remembering the orientation of a
pushbutton

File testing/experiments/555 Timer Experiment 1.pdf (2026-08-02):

# Hypothesis :

By connecting the power,

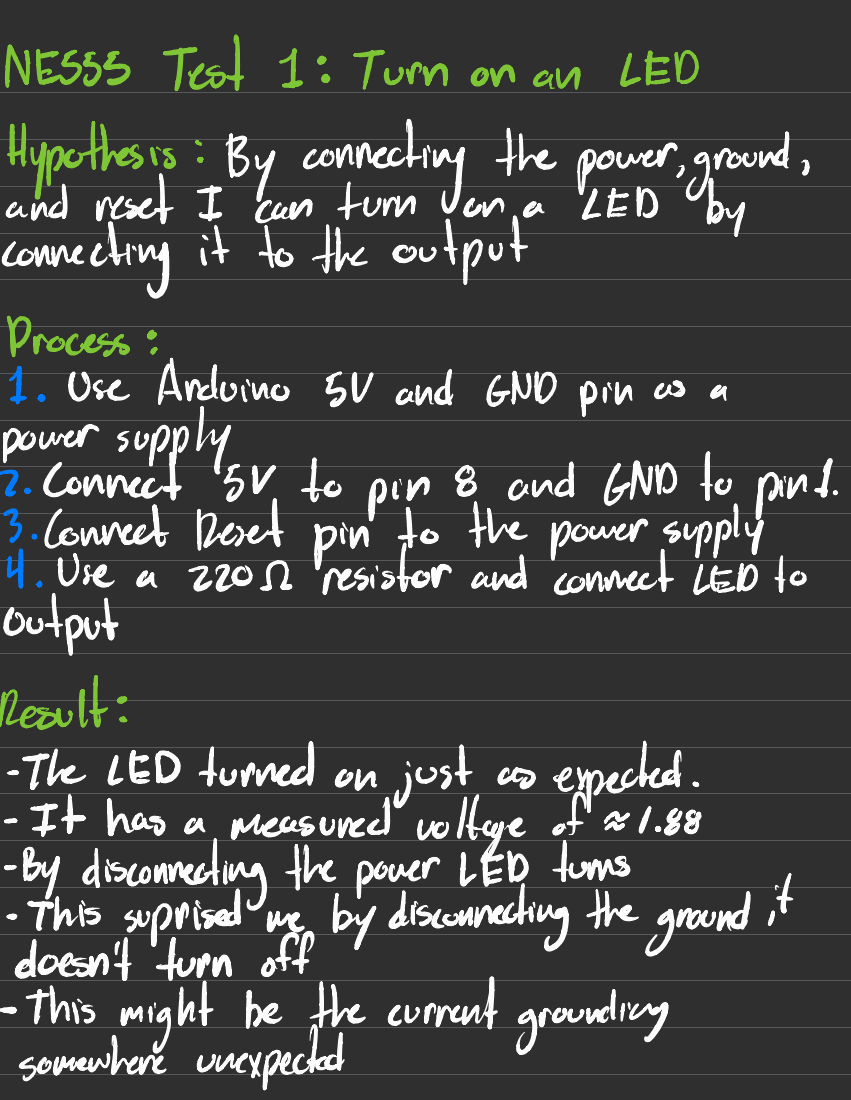
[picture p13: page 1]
NESSS Test 1 : Turn on an; LED; ground,; and reset I can turn on a; Use Arduino 5V and GND pin as a

connecting it to the output

Process :
power suppm
2. Connect su to pin 8 and GND to pin1.
3.Connect Reset pin to the power supply 4) Use a 220-
output
Result :
The LED turned on just as expected .
It has a measured voltage of 1.88
By disconnecting the power LED turns
This suprised me by disconnecting theground it
doesn't turn off
This might be the current grounding somewhere unexpected

1 resistor and connect LED to

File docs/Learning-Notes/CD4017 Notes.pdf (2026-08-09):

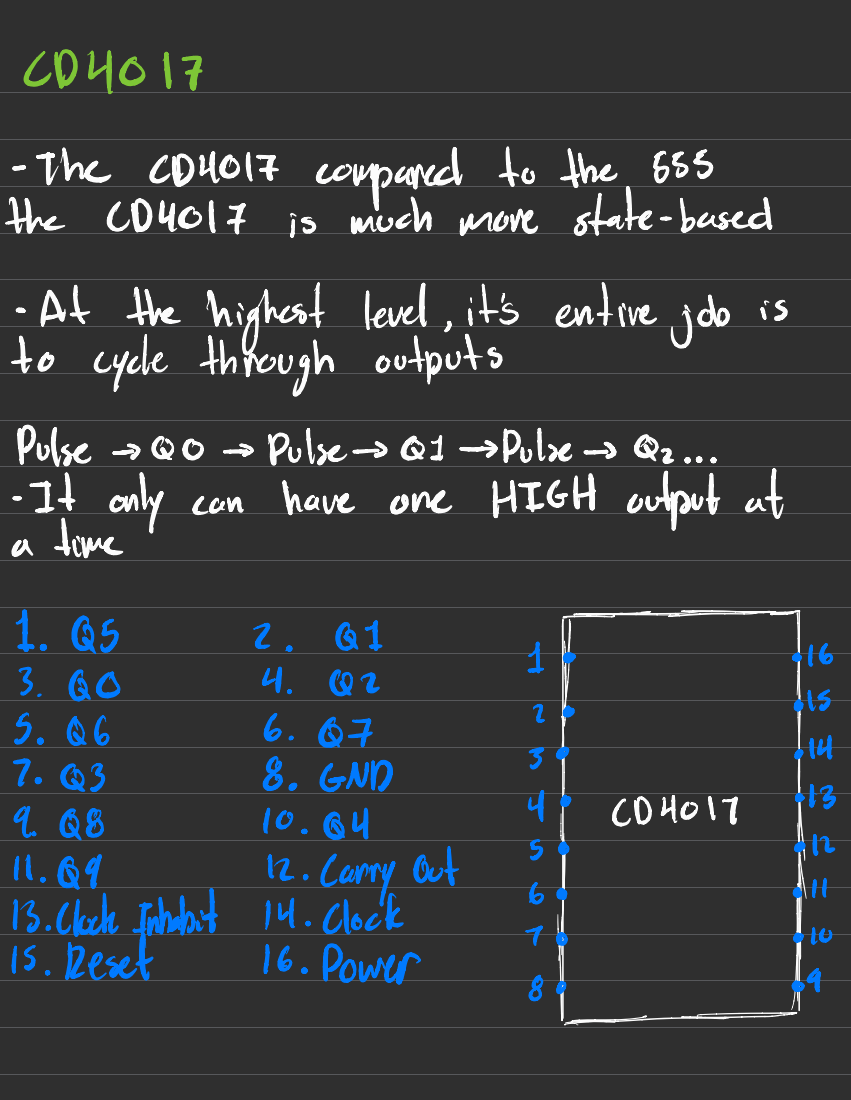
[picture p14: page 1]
The CD4017; to the 555 compared the CD4017 is; much more state-based; Pulse -00 -> Pulse⁻ > 01--poke - > Q2 ...; It only can; have one; HIGH output at; a time; par ⁷. Q3; GND; out Carry; 14 . .Clock Inhabit; Cloake; Reset; Power

- At the highest level ,
to cycle through outputs

it's entire job is

# Arguable the most important pin

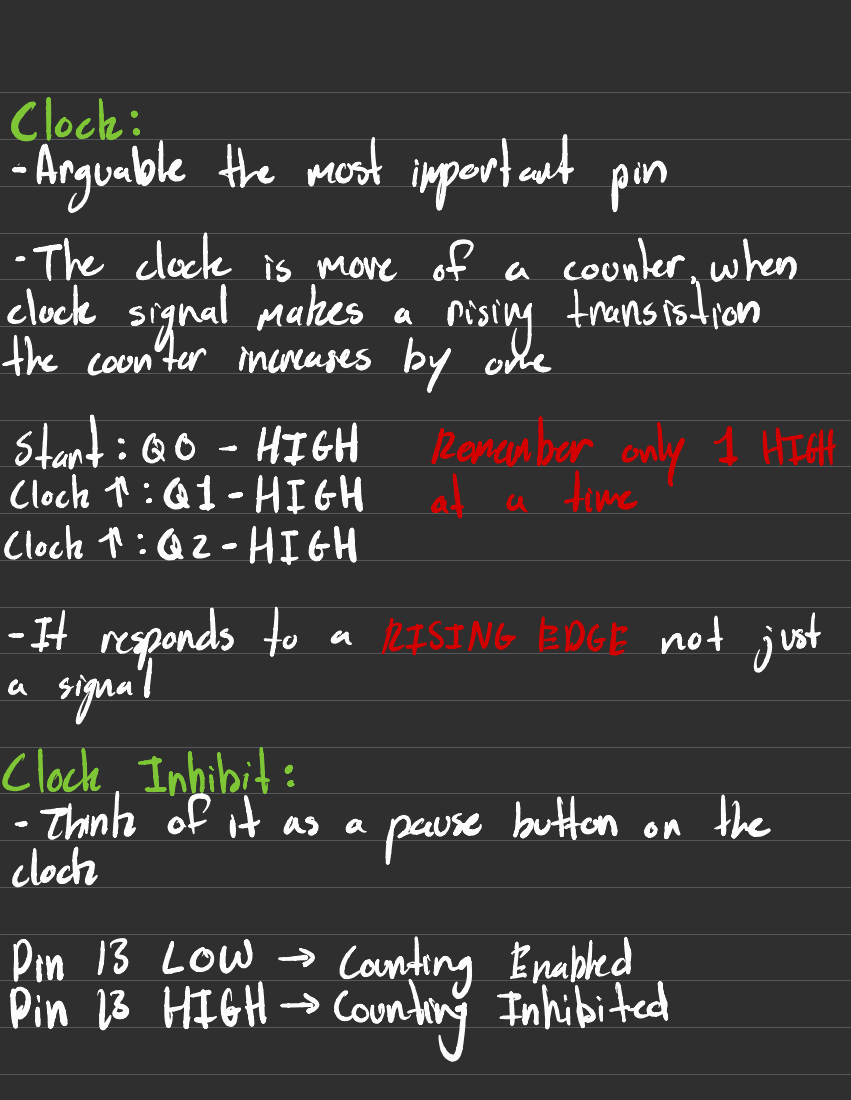
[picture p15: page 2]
Clock :; The clock is more; counter,; when; one; Start : Q0-HIGH; Remember only 1 HIGH; Clock + :Q1-HIGH; time; HIGH; It responds to a; RISING EDGE not just a; pause button on; the; Pin 13 Low - >; Counting Enabled; Pin 13 HIGH ⁻ >; counting Inhibited

looksignalmakes arising transistinone

Clock + : Q2 -
signal
Clock Inhibit :
Think of it as a
clock

## IfLou the clock counts normally

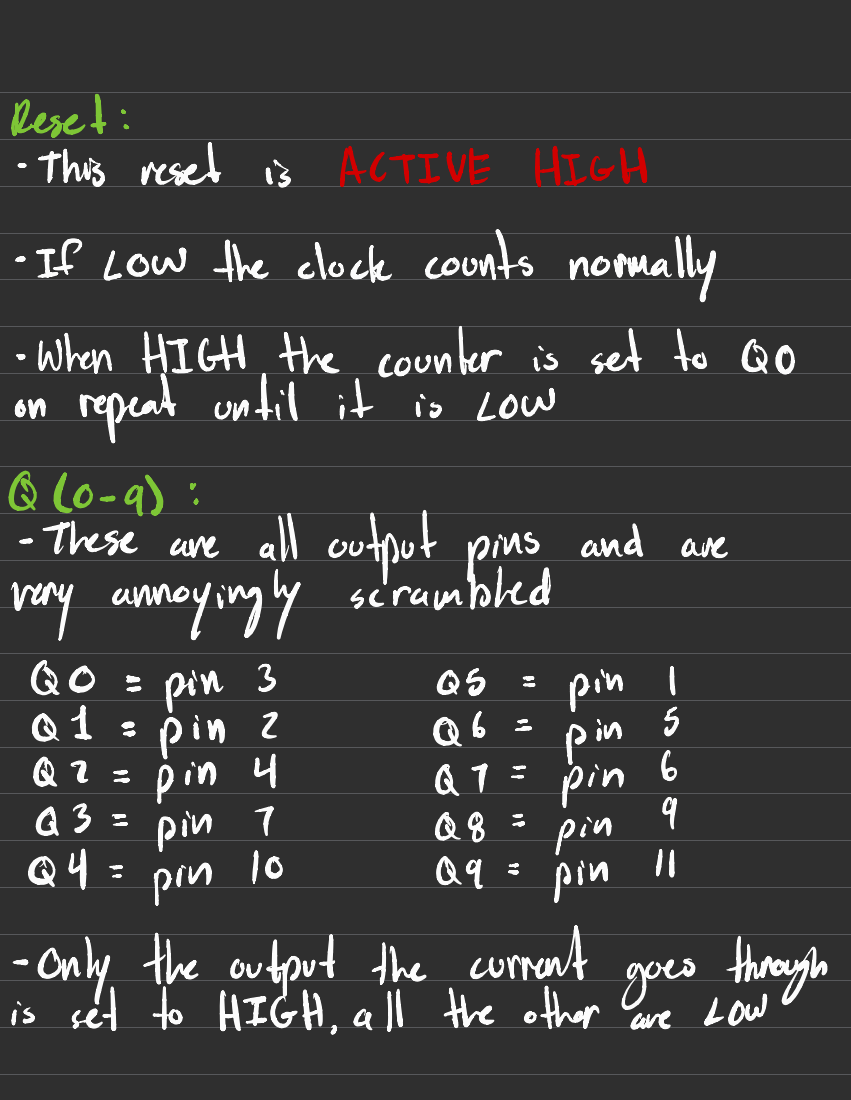
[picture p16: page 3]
Reset :; This resed is; ACTIVE HIGH; repeat until it is; Low; These are; all output pins and are; scrambled; very annoyingly; pin; Rinse; ⑳bin Q2 =; S pin; pin i

When HIGH the counter is set toQo

-Only the outputthecurrent goesthrong a

# It produces a slow repeating signal that trigger every 10 clock ticles

out :; Carry This is an; output that is; used different; then 20-09; 10 counts -; 1 Larry out; Typically used in; some chain of CD4017; East Counter -0-9 - > Slow Counter 17

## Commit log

2026-08-02 555 Relay work, experiments
    Eventually will add a markup for experiments in a format to be read without external program and will use the pdf as reference
2026-08-05 NE555 Relay Research
2026-08-14 KiCad and TinkerCad work
    [LED_Hardware_Heart-First_Design.kicad_sch]
2026-08-16 Soldering Session
2026-08-17 Breadboard Complete
    [LED_Hardware_Heart-Final Design.kicad_sch]
2026-08-18 NE555 Soldered
2026-08-20 Finishing the board
